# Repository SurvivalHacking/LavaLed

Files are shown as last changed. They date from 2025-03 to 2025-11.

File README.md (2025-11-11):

# LAVALED

EPXX-LavaLED
---
# Description

In the 1970s it was a must-have in every home: a luminous ornament with futuristic and magical appeal. The lava lamp, with its hypnotic effect of floating magma, captivated everyone. Today, this timeless classic is back in a new electronic guise, with spectacular effects and smart control via Alexa. A mix of nostalgia and innovation, ready to amaze!
---

# 👨‍💻 Program via web broser (Chrome)

https://davidegatti.altervista.org/
---

# 🌆 Images







---
## 🎛️ Schematic
Screenshot 2025-11-11 alle 22 48 39

---
## 🎛️ BOM
* 16x16 RGB Matrix AMZ: https://amzn.to/4il5OQh
* 16x16 RGB Matrix ALI: https://s.click.aliexpress.com/e/_DFRyDXJ
* ESP32C3 AMZ: https://amzn.to/4kt5G2W
* ESP32C3 ALI: https://s.click.aliexpress.com/e/_DDST7Bj
* Capacitive pushbutton Capacitivi AMZ: https://amzn.to/438dXD7
* Capacitive pushbutton ALI: https://s.click.aliexpress.com/e/_onoDssm
* Transparent filament AMZ: https://amzn.to/3R7phbv
* Affiliate links
 
---
## 🧾 License

This project is distributed under the **Creative Commons Attribution-NonCommercial 4.0 International (CC BY-NC 4.0)** license.

## Rights granted
* Copy and redistribute the material in any format or medium.
* Create derivative works, remixes, and adaptations.

## Conditions
* **Attribution**: You must give appropriate credit, provide a link to the license, and indicate if changes were made.
* **NonCommercial**: You may not use the material for commercial purposes.

## Further information
For the full text of the license, visit <https://creativecommons.org/licenses/by-nc/4.0/>.

---

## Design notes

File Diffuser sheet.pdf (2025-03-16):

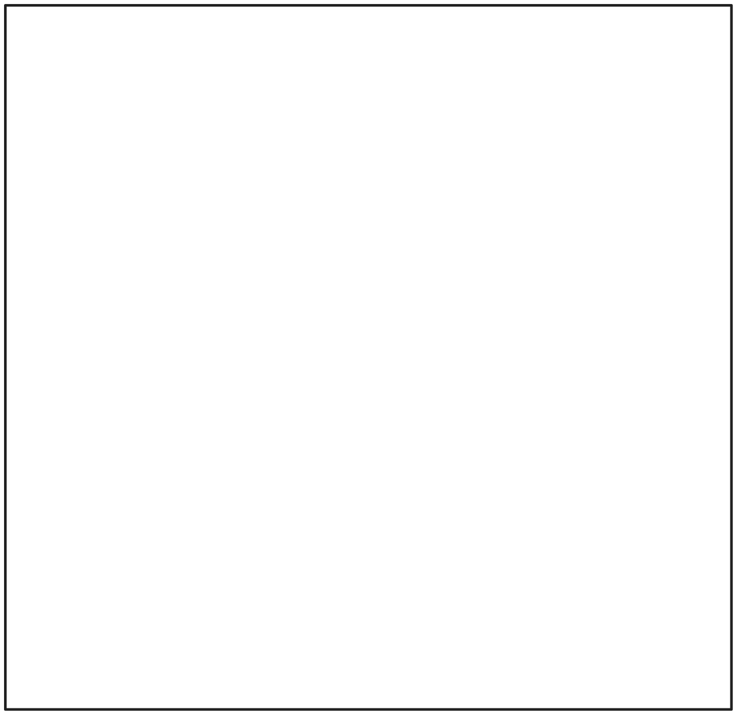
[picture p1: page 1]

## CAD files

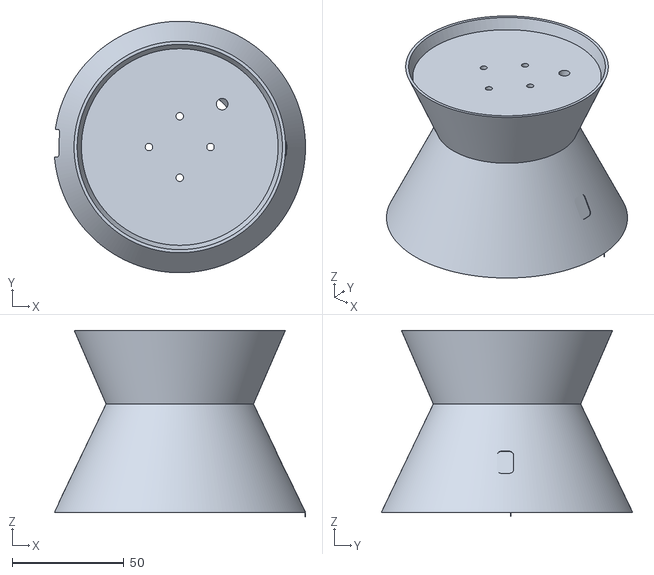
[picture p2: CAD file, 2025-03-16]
3D/Base.stl
112.3 x 112.5 x 83.4

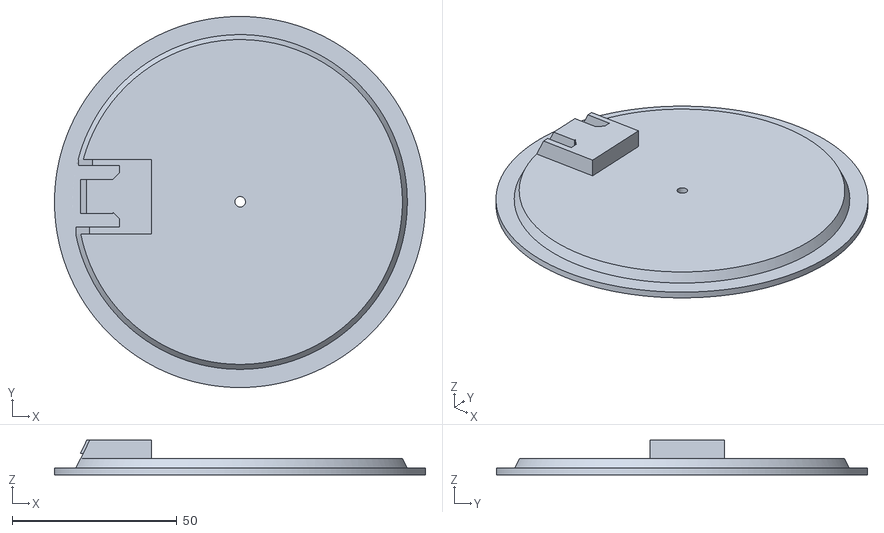
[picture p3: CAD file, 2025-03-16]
3D/Bottom cover.stl
112.5 x 112.5 x 10.5

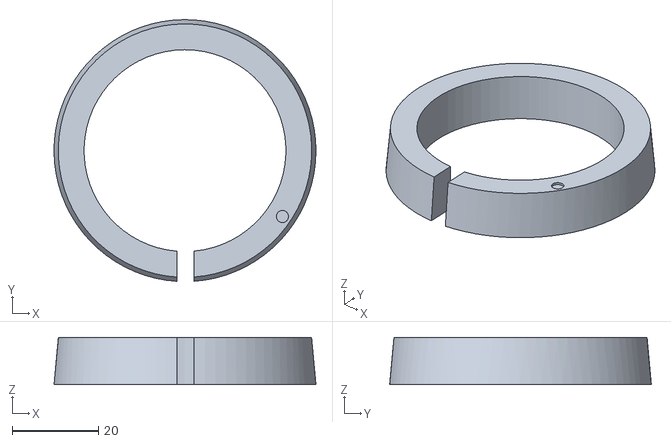
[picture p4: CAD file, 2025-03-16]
3D/Spacer.stl
60.9 x 60.9 x 11.0

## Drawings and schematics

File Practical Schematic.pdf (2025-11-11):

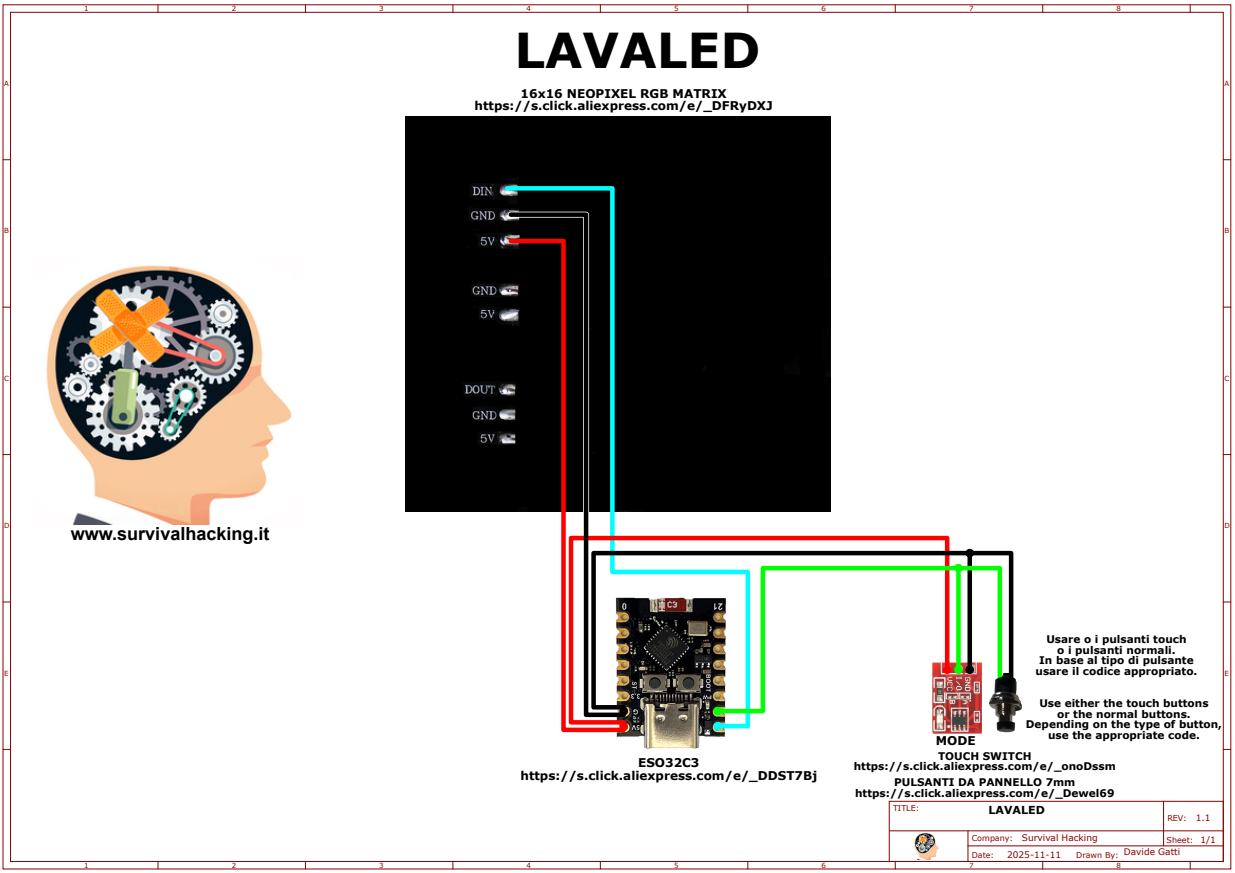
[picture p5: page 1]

https://s.click.aliexpress.com/e/_DFRyDXJ

Usare o i pulsanti touch
o i pulsanti normali.
In base al tipo di pulsante
usare il codice appropriato.

Use either the touch buttons
or the normal buttons.
Depending on the type of button,
use the appropriate code.

https://s.click.aliexpress.com/e/_DDST7Bj

https://s.click.aliexpress.com/e/_onoDssm

https://s.click.aliexpress.com/e/_Dewel69

TITLE: LAVALED | REV: 1.1

Company: Survival Hacking | Sheet: 1/1

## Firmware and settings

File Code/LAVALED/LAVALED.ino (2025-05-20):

// 02/03/2025
// LavaLED -  By Davide Gatti SURVIVAL HACKING  www.gattidavide.it
//
// Short press button = change brightness
// long press button = change preset
// button pressed at startup = forget wifi information
// with Alexa is possible to control brightness and solid color. Black color = Lava effects
//
// 20/05/2025
// added button type management
// BUTTON_LOGIC_INVERTED = 1 for normal NA pushbutto tied to GND
// BUTTON_LOGIC_INVERTED = 0 for touch button

// Include and base definition 
#include <stdio.h>
#include <string>
#include <FastLED.h>     // https://github.com/FastLED/FastLED 
#include "fl/json.h"
#include "fl/slice.h"
#include "fx/fx_engine.h"
#include "fx/2d/animartrix.hpp"
#include "fl/ui.h"
#include <WiFi.h> 
#include <ESPmDNS.h>
#include <ArduinoOTA.h>
#include <Espalexa.h>    // https://github.com/Aircoookie/Espalexa
#include <EEPROM.h>      // https://github.com/jwrw/ESP_EEPROM 
#include <WiFiManager.h> // https://github.com/tzapu/WiFiManager

// Button Type selection
// BUTTON_LOGIC_INVERTED = 1 for normal NA pushbutto tied to GND
// BUTTON_LOGIC_INVERTED = 0 for touch button
#define BUTTON_LOGIC_INVERTED 0

using namespace fl;

// p configuration
#define LED_PIN      5     // for LED matrix
#define BUTTON_MODE  6     // pushbutton
#define LONG_PRESS_TIME 1000  

#define LED_TYPE    WS2812B
#define COLOR_ORDER GRB
#define BRIGHTNESS 10
#define MATRIX_WIDTH  16
#define MATRIX_HEIGHT 16
#define NUM_LEDS (MATRIX_WIDTH * MATRIX_HEIGHT)
#define MAX_MATRIX_MODE 255
#define EFFECT_TIME 30000    // 30 seconds time for auto change effects

#define FIRST_ANIMATION POLAR_WAVES
#define FASTLED_ANIMARTRIX_LICENSING_AGREEMENT  1

// EEPROM management
#define EEPROM_SIZE 10   // eprom size
#define EEPROM_CONFIGURED_MARKER 0x55
#define EEPROM_MODE_ADDR 1
#define EEPROM_BRIGHT_ADDR 2

CRGB leds[NUM_LEDS];

XYMap xyMap = XYMap::constructRectangularGrid(MATRIX_WIDTH, MATRIX_HEIGHT);

Animartrix animartrix(xyMap, FIRST_ANIMATION);
FxEngine fxEngine(NUM_LEDS);

Espalexa espalexa;

// global variables
int currentMode = 0;
uint8_t currentBright = 10;
uint8_t alexaOff = 0;
uint8_t timeSpeed = 0.1;
uint8_t brightness = 10;
uint8_t fxIndex =1;
uint8_t autoMode =1;
uint8_t firstAuto =1;

// Main setup
void setup() {
   Serial.begin(115200);
   Serial.println("START");
   EEPROM.begin(EEPROM_SIZE);
   
   // read configuration
   if (EEPROM.read(0) != EEPROM_CONFIGURED_MARKER) {
       // first configuration
       EEPROM.write(0, EEPROM_CONFIGURED_MARKER);
       EEPROM.write(EEPROM_MODE_ADDR, 1);    // Preset default
       EEPROM.write(EEPROM_BRIGHT_ADDR, 1);  // Seconds Blink default default
       EEPROM.commit();                      // Important for ESP32!
   }
   
   // Load saved preset
   autoMode = EEPROM.read(EEPROM_MODE_ADDR);
   currentBright = EEPROM.read(EEPROM_BRIGHT_ADDR);
    
   // Pin configuration
   pinMode(BUTTON_MODE, INPUT_PULLUP);
  
   // I/O pin configuration
   #if BUTTON_LOGIC_INVERTED == 1
     // inverted logic: pull-up, push = GND (LOW)
     pinMode(BUTTON_MODE, INPUT_PULLUP);
     bool isModeButtonPressed = !digitalRead(BUTTON_MODE);
   #else
     // normal logic: pull-down, push = VCC (HIGH)
     pinMode(BUTTON_MODE, INPUT_PULLDOWN);
     bool isModeButtonPressed = digitalRead(BUTTON_MODE); 
   #endif

   if(isModeButtonPressed) {
   // Show rest wit red led blinking
      for(int i = 0; i < 5; i++) {
        fill_solid(leds, NUM_LEDS, CRGB::Red);
        FastLED.show();
        delay(100);
        FastLED.clear();
        FastLED.show();
        delay(100);
      }
      Serial.println("Reset WiFi");
      resetWiFi();
   }

   // Inizializzazione FastLED
   FastLED.addLeds<WS2811, LED_PIN, COLOR_ORDER>(leds, NUM_LEDS)
       .setCorrection(TypicalLEDStrip)
       .setScreenMap(xyMap);
   FastLED.setBrightness(currentBright);
   fxEngine.addFx(animartrix);
   animartrix.fxSet(currentMode);

   // WiFiManager Manager
   WiFiManager wm;
   
   // portal timeout (opzional)
   wm.setConfigPortalTimeout(180); // 3 minutes
   
   // Personalize WIFI portale
   wm.setTitle("LAVALED WiFi Setup");
   
   // Show blu led during config
   fill_solid(leds, NUM_LEDS, CRGB::Blue);
   // leds[0] = CRGB::Blue;
   FastLED.setBrightness(10);
   FastLED.show();
   
   // try to start or portal config
   bool res = wm.autoConnect("LAVALED_AP");

   if(!res) {
       Serial.println("Connection failed");
       // Show error wit RED led
       fill_solid(leds, NUM_LEDS, CRGB::Red);
       FastLED.show();
       delay(3000);
       ESP.restart();
   } 
   else {
       // Connected
       Serial.println("WiFi Connected!");
       // Show success with green led
       fill_solid(leds, NUM_LEDS, CRGB::Green);
       FastLED.show();
       delay(1000);
       FastLED.clear();
       FastLED.show();
   }
   
   // Post WIFI configuration
   WiFi.setSleep(false);
   WiFi.setAutoReconnect(true);
   
   if(WiFi.status() == WL_CONNECTED) {
       setupOTA();
       espalexa.addDevice("LAVALED", deviceControl);
       espalexa.begin();
   }
//   updateDisplay();
}
void resetWiFi() {
    WiFiManager wm;
    wm.resetSettings();
    ESP.restart();
}
// Setup OTA
void setupOTA() {
   ArduinoOTA.setHostname("LAVALED");
   
   ArduinoOTA.onStart([]() {
       FastLED.clear();
       FastLED.show();
   });
   
   ArduinoOTA.onProgress([](unsigned int progress, unsigned int total) {
       uint8_t percentComplete = (progress / (total / 100));
       fill_solid(leds, map(percentComplete, 0, 100, 0, NUM_LEDS), CRGB::Blue);
       FastLED.show();
   });
   
   ArduinoOTA.begin();
}


// Main Loop
void loop() {
   static uint32_t lastUpdate = 0;
   static uint32_t lastButtonCheck = 0;
   static uint32_t lastMatrixUpdate = 0;
   static uint32_t lastPresetChange = 0;
   uint32_t currentMillis = millis();
   CRGB my_color = CRGB::Black;
    

   // OTA Management and network
   if(WiFi.status() == WL_CONNECTED) {
       ArduinoOTA.handle();
   }
  
   // Check button every 50ms
   if(currentMillis - lastButtonCheck > 50) {
       checkButtons();
       lastButtonCheck = currentMillis;
   }

    // Check preset chancge 30s
    if(currentMillis - lastPresetChange > EFFECT_TIME) {
      changeMode();
      lastPresetChange = currentMillis;
    }

   switch (autoMode) {
      case 0:
        my_color = CRGB::Black;
        break;
      case 1:
        // Manage matrix related to mode
        if (alexaOff==0) {                 // if power off through Alexa
            FastLED.setBrightness(currentBright);
            fxEngine.setSpeed(timeSpeed);
            fxEngine.draw(millis(), leds);
            FastLED.show();
        }
        break;
      case 2:
        my_color = CRGB::White;
        break;
      case 3:
        my_color = CRGB::Red;
        break;
      case 4:
        my_color = CRGB::Green;
        break;
      case 5:
        my_color = CRGB::Blue;
        break;
      case 6:
        my_color = CRGB::AntiqueWhite;
        break;
      case 7:
        my_color = CRGB::Gold;
        break;
      case 8:
        FastLED.setBrightness(currentBright);
        break;

   }
   if (firstAuto==1 && autoMode != 1) {   
      fill_solid(leds, NUM_LEDS, my_color);
      FastLED.show();
      firstAuto=0;
   } 

   // Chel Alexa every second
   if(WiFi.status() == WL_CONNECTED && currentMillis - lastUpdate > 2000) {
//       Serial.println("Check Alexa"); 
       espalexa.loop();   
       lastUpdate = currentMillis;
   }

   yield();
}

void checkButtons() {
    static unsigned long pressStartTime = 0;
    static unsigned long lastLongPressTime = 0;
    static bool buttonWasPressed = false;
    static bool longPressActive = false;

    // Read button state according to loigc selected
    #if BUTTON_LOGIC_INVERTED == 1
      // inverted logic: pull-up, push = GND (LOW)
      bool buttonState = digitalRead(BUTTON_MODE);
    #else
      // normal logic: pull-down, push = VCC (HIGH)
      bool buttonState = !digitalRead(BUTTON_MODE);
    #endif

    if (buttonState == LOW) {  // button is pressed
        if (!buttonWasPressed) {  // first press of button detected
            pressStartTime = millis();
            buttonWasPressed = true;
        }
        
        if ((millis() - pressStartTime >= LONG_PRESS_TIME) && !longPressActive) {
            longPressActive = true;  // activate long press function
        }

        if ((millis() - pressStartTime >= LONG_PRESS_TIME) && 
            (millis() - lastLongPressTime >= LONG_PRESS_TIME)) { 
            longPressActive = true;
            lastLongPressTime = millis();  //record last long press event
            autoMode+=1;
            if (autoMode>=8) {
              autoMode=0;    
            }  
            firstAuto=1;
            Serial.print("Auto="); 
            Serial.println(autoMode); 
            EEPROM.write(EEPROM_MODE_ADDR, autoMode);
            EEPROM.commit();
        }

    } else {  // button is released
        if (buttonWasPressed && !longPressActive) {
          currentBright += 10;
          if(currentBright >= 128) currentBright=0;
          FastLED.setBrightness(currentBright);
          Serial.print("Brigthness="); 
          Serial.println(currentBright); 
          EEPROM.write(EEPROM_BRIGHT_ADDR, currentBright);
          EEPROM.commit();
          FastLED.show();
        }
        buttonWasPressed = false;
        longPressActive = false;
    }
}

void changeMode() {
    currentMode += 1;
    if(currentMode >= MAX_MATRIX_MODE) currentMode=0;
    animartrix.fxSet(currentMode);
    Serial.print("Mode="); 
    Serial.println(currentMode); 
}


void deviceControl(uint8_t brightness, uint32_t rgb) {
   if (brightness == 0) {
      alexaOff=1;  
      FastLED.clear();
      FastLED.show();
      return;
   } else {
      alexaOff=0;
   } 

   if  (brightness >= 128) brightness=128; // limit brightness to 128 for reduce current
 
   // Convert Alex RGB color with CRGB for FastLED
   CRGB newColor;
   newColor.r = (rgb >> 16) & 0xFF;
   newColor.g = (rgb >> 8) & 0xFF;
   newColor.b = rgb & 0xFF;

   Serial.print("COLOR="); 
   Serial.println(rgb); 

   // Update colours
   if (rgb == 16777215) {           //16777215=black
     autoMode=1; 
   } else {
     autoMode=8;
     fill_solid(leds, NUM_LEDS, newColor);
   }    

   currentBright=brightness;
   FastLED.setBrightness(currentBright);
   EEPROM.write(EEPROM_BRIGHT_ADDR, currentBright);
   EEPROM.commit();
   FastLED.show();
   firstAuto=0;
}
 

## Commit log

2025-03-16 3D printer files
    [Base.stl, Bottom cover.stl, Spacer.stl]
2025-03-16 Practical Schematic
2025-03-16 Bill Of material
2025-03-16 ESP32 Code
2025-11-11 Update README with schematic and BOM details
    Added schematic and BOM sections with affiliate links.
